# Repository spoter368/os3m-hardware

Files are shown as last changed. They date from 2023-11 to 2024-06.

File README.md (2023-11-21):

# os3m-hardware
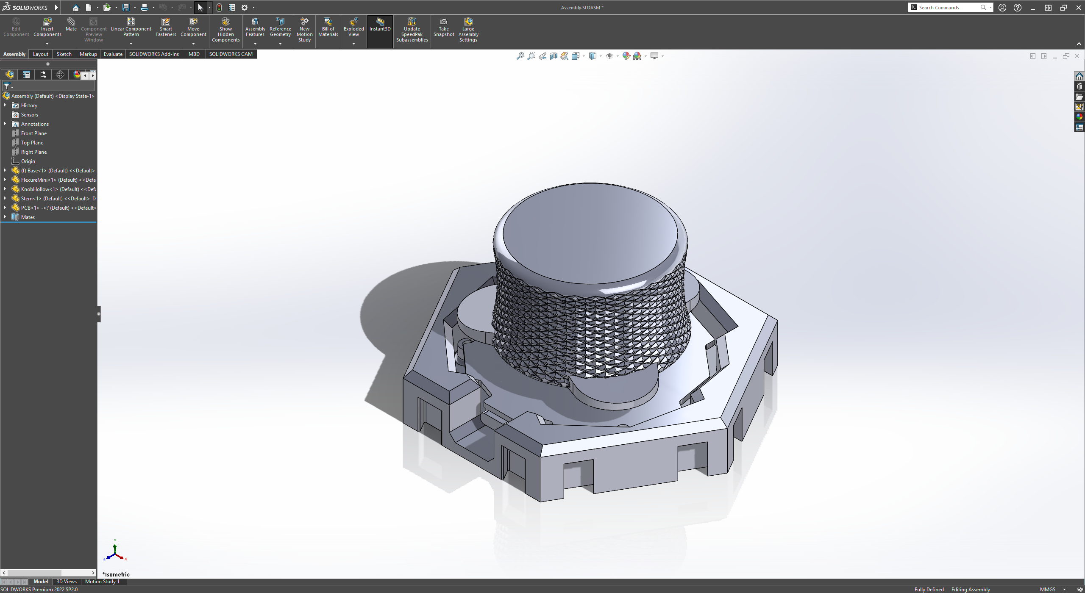
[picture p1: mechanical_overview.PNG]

Welcome to the mechanical repository of the OS3M mouse! Here you'll find all the pieces you need to make your own OS3M mouse, with the exception of 9 * M3x10 fasteners, the PCB and 3 dimes (USA 10 cent coin). I try to only commit and push when I have a fully compatible set of parts, so at any given time you should be able to clone this repo and build your own using its contents.

One of the beautiful things about this mouse is that if you don't like some aspect of it, you can just change it! Particularly when it comes to the flexure inside the mouse, if you want more or less stiffness, fork and edit away! Feel free to leave any issues in the issues tab as you find them.

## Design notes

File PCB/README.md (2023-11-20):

# OS3M Mouse PCB
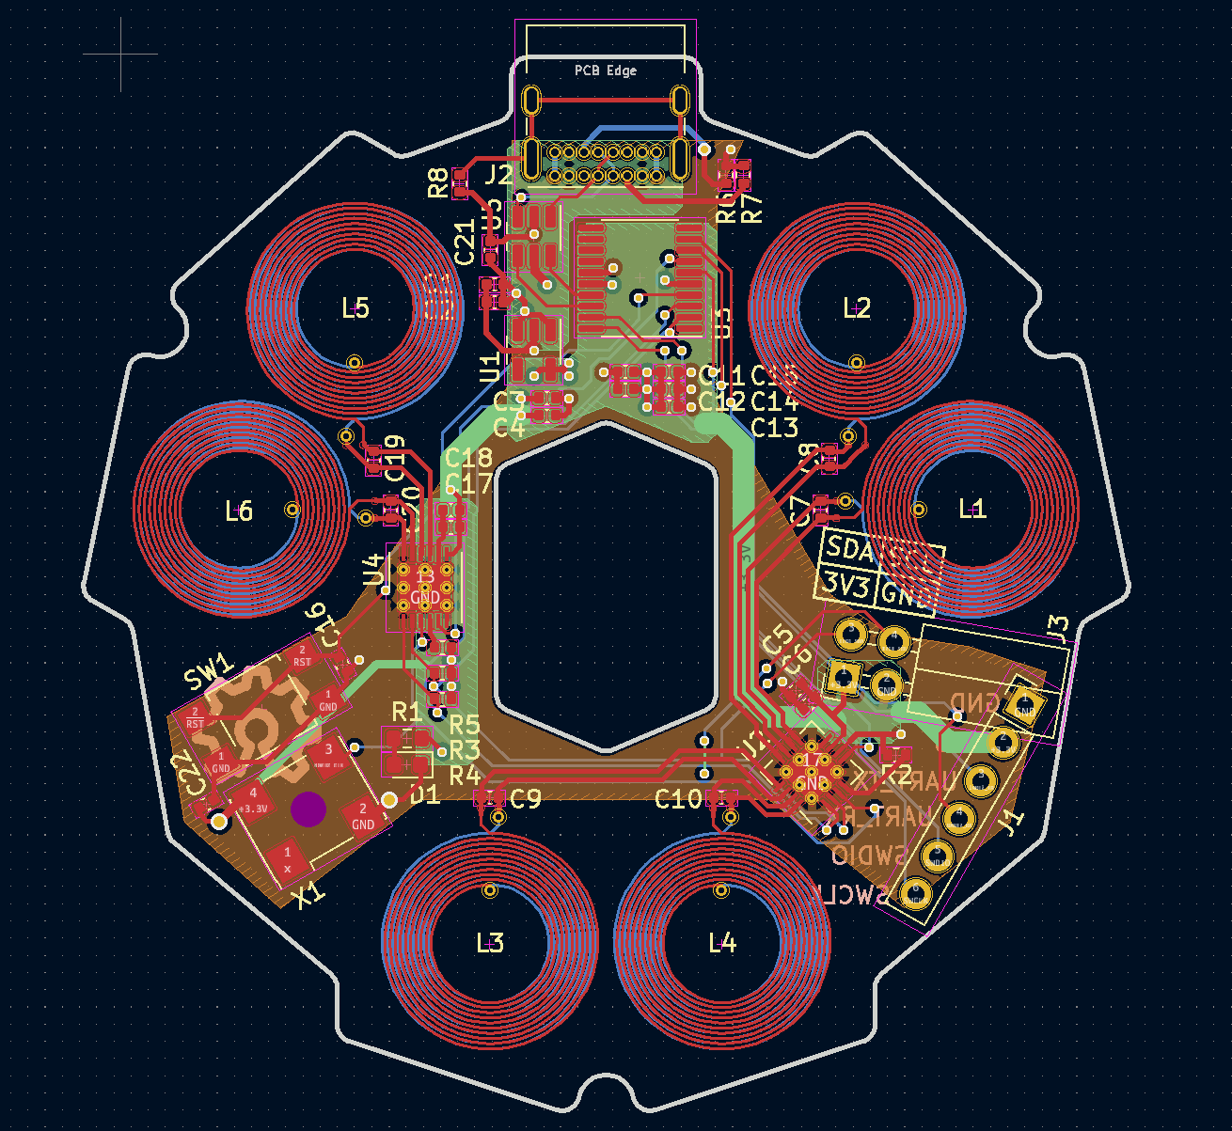
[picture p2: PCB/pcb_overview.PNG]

Here are all the files pertaining to the OS3M mouse's PCB. I only commit and push here when I have a full revision update to the PCB. So far there are only 2 revisions, 0 and 1, and you should only make the current one (1). Gerbers can be found in the os3m-gerbers folder, and can be sent to JLC for easy fab. I also plan on selling these on tindie at some point.

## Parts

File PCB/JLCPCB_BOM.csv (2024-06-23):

Comment | Designator | Footprint | JLCPCB Part# | Quantity
10u | C1, C4, C5, C17 | Capacitor_SMD:C_0402_1005Metric | C15525 | 4
1u | C2, C3, C6, C14, C16, C18 | Capacitor_SMD:C_0402_1005Metric | C52923 | 6
1n | C7, C8, C9, C10, C19, C20 | Capacitor_SMD:C_0402_1005Metric | C126493 | 6
10n | C11, C22 | Capacitor_SMD:C_0402_1005Metric | C15195 | 2
100n | C12, C13, C21 | Capacitor_SMD:C_0402_1005Metric | C1525 | 3
4.7u | C15 | Capacitor_SMD:C_0402_1005Metric | C23733 | 1
BLUE_LED | D1 | LED_SMD:LED_0603_1608Metric | C389520 | 1
200 | R1 | Resistor_SMD:R_0603_1608Metric | C22962 | 1
5.1k | R2, R3, R4, R5, R6, R7 | Resistor_SMD:R_0402_1005Metric | C25905 | 6
1M | R8 | Resistor_SMD:R_0402_1005Metric | C26083 | 1
SW_Push | SW1 | Button_Switch_SMD:SW_SPST_TL3305A | C92581 | 1
AP2112K-3.3 | U1 | Package_TO_SOT_SMD:SOT-23-5 | C51118 | 1
LDC1614 | U2 | Package_DFN_QFN:WQFN-16-1EP_4x4mm_P0.5mm_EP2.6x2.6mm_ThermalVias | C968448 | 1
STM32F042F6P6 | U3 | Package_SO:TSSOP-20_4.4x6.5mm_P0.65mm | C2969989 | 1
LDC1612 | U4 | Package_SON:WSON-12-1EP_4x4mm_P0.5mm_EP2.6x3mm_ThermalVias | C1847959 | 1
USBLC6-2SC6 | U5 | Package_TO_SOT_SMD:SOT-23-6 | C2687116 | 1
USB_C_Receptacle_USB2.0 | J2 | Connector_USB:USB_C_Receptacle_XKB_U262-16XN-4BVC11 | C319148 | 1
XTAL_40MHz | X1 | Oscillator:Oscillator_SMD_Abracon_ASV-4Pin_7.0x5.1mm | C558764 | 1

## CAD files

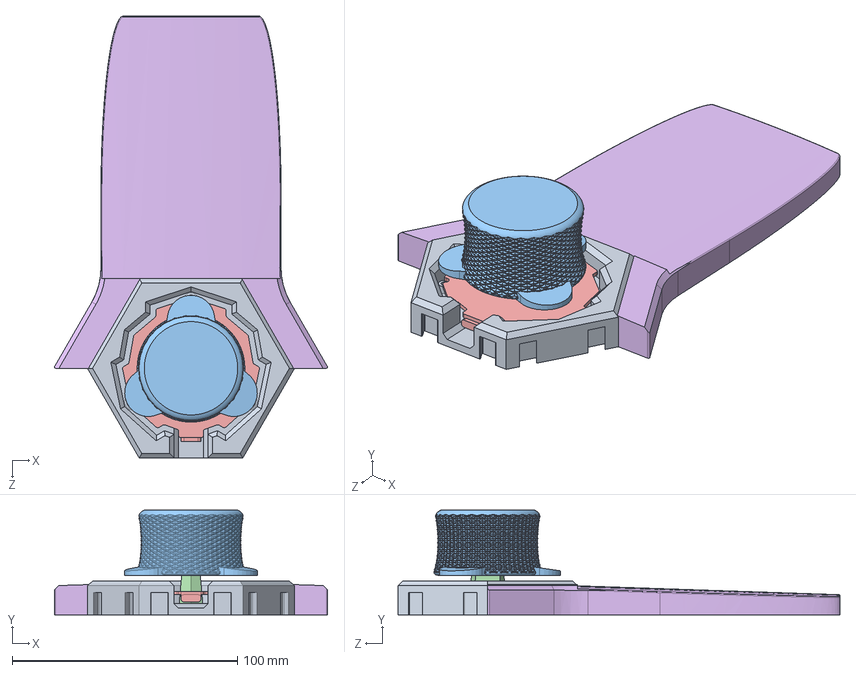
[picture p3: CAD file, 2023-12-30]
Assembly.SLDASM
121.3 x 46.6 x 196.2 mm
Base
FlexureMini
KnobHollow
Stem
PCB
HandRest

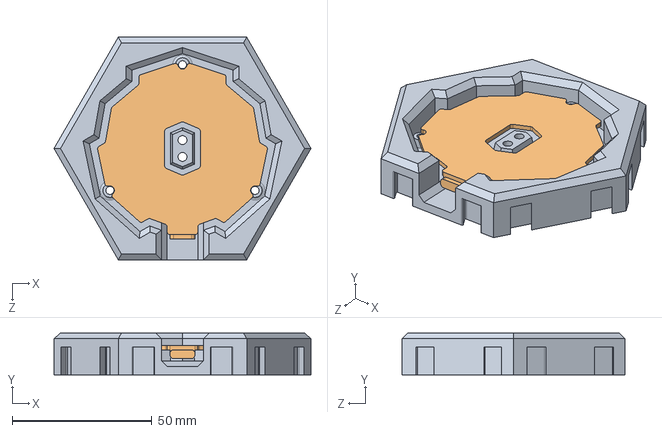
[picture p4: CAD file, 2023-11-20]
PCB_Assem.SLDASM
92.0 x 15.0 x 79.7 mm
Base
PCB

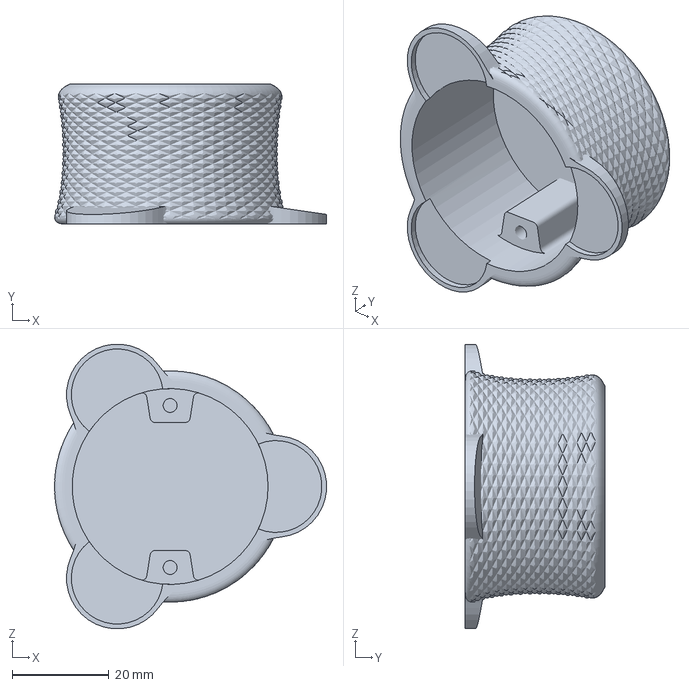
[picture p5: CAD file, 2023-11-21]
3MF Files/KnobHollow.3MF
56.2 x 29.0 x 58.8 mm

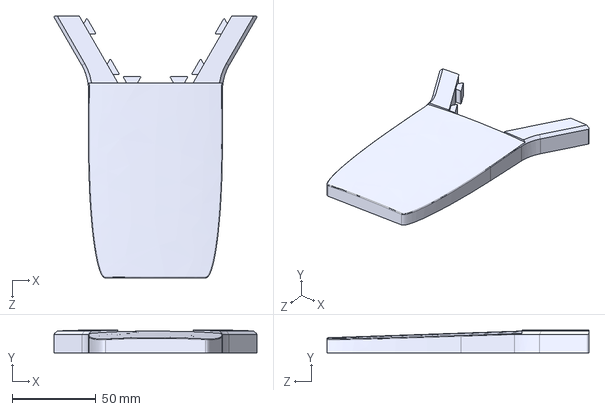
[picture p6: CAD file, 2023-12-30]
Step Files/HandRest.STEP
121.3 x 13.5 x 156.4 mm

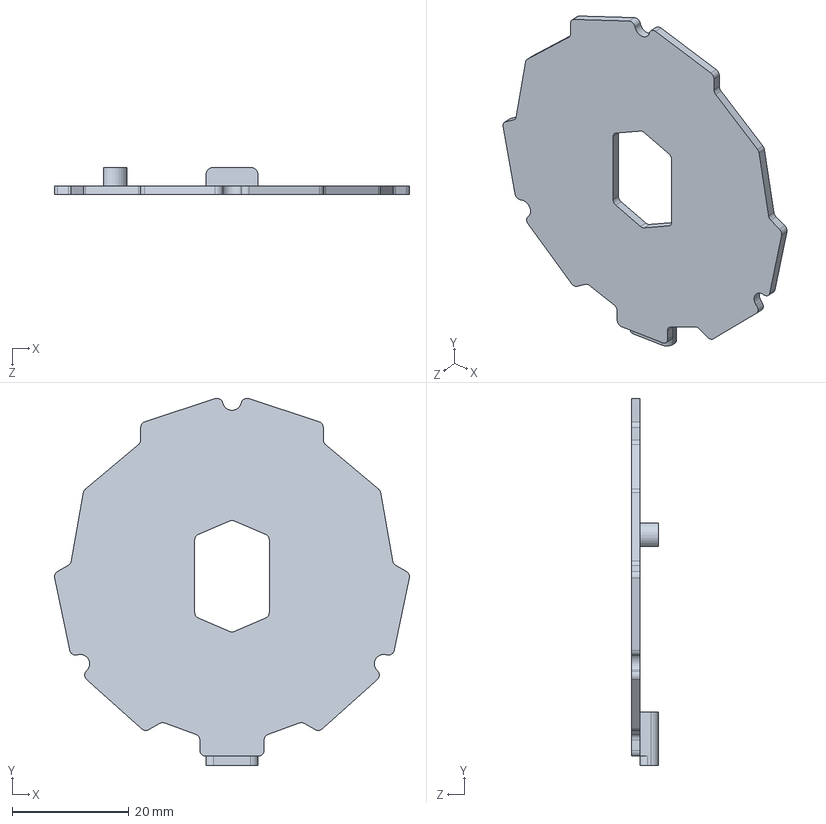
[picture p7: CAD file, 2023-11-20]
PCB.SLDPRT
60.8 x 62.9 x 4.67 mm

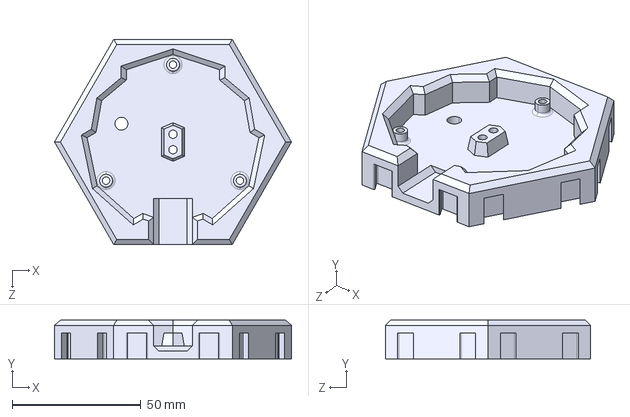
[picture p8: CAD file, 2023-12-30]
Step Files/Base.STEP
92.0 x 15.0 x 79.7 mm

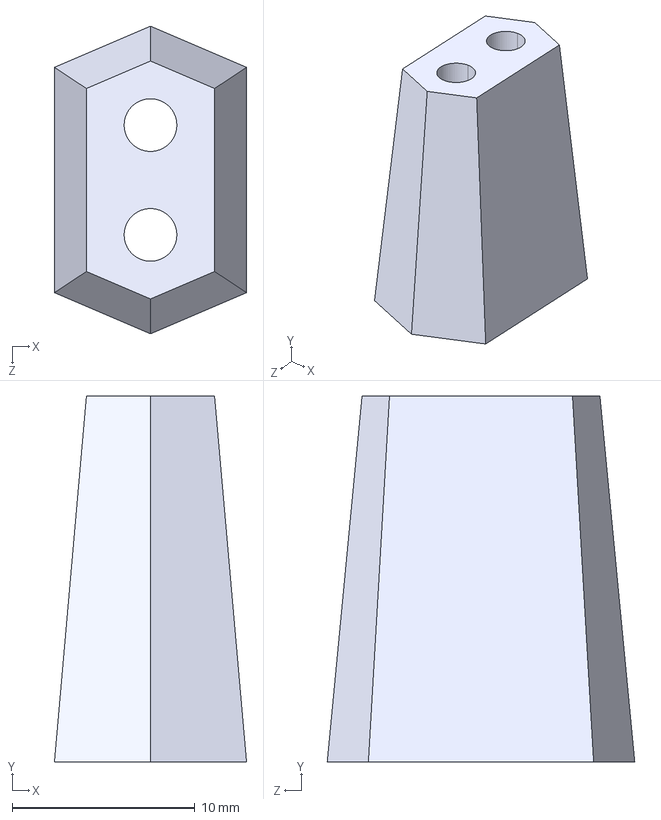
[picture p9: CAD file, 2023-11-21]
Step Files/Stem.STEP
10.5 x 20.0 x 16.8 mm

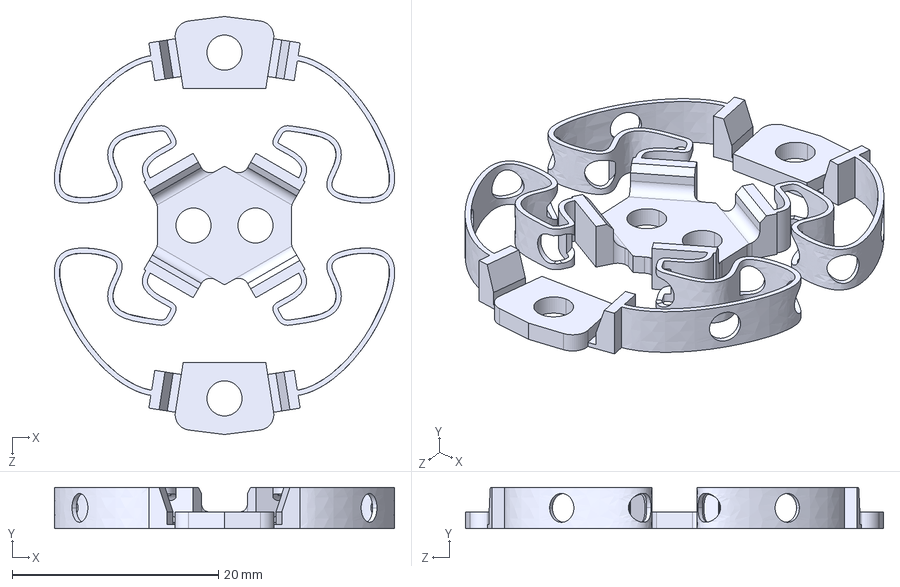
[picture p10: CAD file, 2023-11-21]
Step Files/FlexureMini.STEP
33.0 x 4.00 x 40.5 mm

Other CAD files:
3MF Files/Base.3MF
3MF Files/FlexureMini.3MF
3MF Files/HandRest.3MF
3MF Files/Stem.3MF
Base.SLDPRT
FlexureMini.SLDPRT
HandRest.SLDPRT
Stem.SLDPRT

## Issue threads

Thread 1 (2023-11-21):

Document software needed and BOM

MarcusWolschon, 2023-11-21:
Please document what software is needed to open the files.
My Alibre Design/3D Systems  Geomagic Design uses SLD_ASM and SLD_PRT too but refuses to open the files.

A Bill Of Meterials especially for the foreign coins needed would be useful too.

spoter368, 2023-11-21:
Just added STEP and 3MF files as well! SLDPRT and SLDASM files are for Solidworks, my CAD program of choice (though I know it's not the most open source friendly)

Kadah, 2023-12-11:
A BOM for the PCB components would be cool. I see #6 was just added submitted today, how convenient. :+1:

MarcusWolschon, 2023-12-13:
> Just added STEP and 3MF files as well! SLDPRT and SLDASM files are for Solidworks, my CAD program of choice (though I know it's not the most open source friendly)

Thanks.
However, I suggest to add that info to the .md instead. ;)

spoter368, 2023-12-27:
No, unfortunately the type-C connector I used has no equivalent on LCSC, so a redesign is needed for JLC to be able to build it. I plan on doing another hardware redesign as soon as this weekend to rectify that issue, though, so keep your eyes open for updates.

moth4017, 2023-12-27:
> No, unfortunately the type-C connector I used has no equivalent on LCSC, so a redesign is needed for JLC to be able to build it. I plan on doing another hardware redesign as soon as this weekend to rectify that issue, though, so keep your eyes open for updates.

thanks  for the update , there are a few of us who  have 3d printers  would like to build them , so  as soon as available from JLCPCB we are keen in ordering,  thanks for the reply .

moth4017, 2024-01-02:
do your updates get posted on your logs?

spoter368, 2024-01-02:
No, I just have been responding to issues here as needed. I updated the PCB this weekend so all parts can come from JLC only to find out LCSC is out of the LDC1612! I want to validate the PCB before I commit it here though so people don’t build defective systems. Will keep this ticket updated

JX5S, 2024-01-02:
LDC1612 is in stock, C202191, 289pcs. It's the LDC1614 that's a bit more problematic, only 67pcs

spoter368, 2024-01-03:
Ah, thank you! I promise they were out of stock this past weekend. I just placed my order for the updated board, and if it comes back and works, I will update the repo

spoter368, 2024-01-13:
@moth4017, I just published a release with the files needed to be assembled at JLCPCB

moth4017, 2024-01-15:
cheers Mark

Llybel, 2024-01-17:
> @moth4017, I just published a release with the files needed to be assembled at JLCPCB

Does this include the larger MCU your logs meantion needed? If not the stm32f103 is 64kb and is a preferred part for JLC which means it doesn't get the extended part fee added to PCB assembly costs.

spoter368, 2024-01-17:
Yes, this includes the larger MCU my logs mention. The STM32F103 is not an ideal choice for this project for a number of reasons, one being that it needs an external crystal to use the USB peripheral, rather than the STM32F042 I chose, which can use its internal clock for USB. Thanks for the suggestion though!

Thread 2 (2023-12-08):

Drivers?

krummrey, 2023-12-08:
I'd love to build one, but it seems that the driver side for OSX is missing, right?
Hopefully the project gains some momentum and some smart people come on board and complement the project to make it a usable solution.
Great start!

spoter368, 2023-12-10:
The driver is builtin to the firmware (available at https://github.com/spoter368/os3m-firmware). It is a USB HID device, which is supported by all modern OSs. The software script I wrote (here: https://github.com/spoter368/os3m-software) is currently Windows only, but all that does is convert the HID data (which any OS can receive) into solidworks API calls. It will become more advanced in the future though.

Closed 2023-12-10.

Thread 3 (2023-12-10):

Alternate inductor plane material - not US legal tender

SketchyFletchy, 2023-12-10:
Great concept! Small limitation for non-US citizens is that we don’t have convenient almost-flat discs of Nickel clad copper hanging around.

I’ll try a build just using some cutout thin copper sheet, which should do the job. I’ll give some thin iron strip a try too. Wouldn’t bother with aluminium though.

spoter368, 2023-12-10:
Thanks! I had no idea this project would be anywhere near as popular as it is, so hopefully you can forgive the use of "proprietary" materials ;)

Thin copper sheet should probably work, but will depend on the thickness. You'll need to make sure it's at least a few skin depths thick in order for the sensor to properly register its presence. My go-to resource for targets is TI app note SNOA957B, available here: https://www.ti.com/lit/an/snoa957b/snoa957b.pdf?ts=1702241246361

Section 4.2 actually mentions aluminum as an excellent target material, so I wouldn't rule that out. Best of luck on your build!

Kadah, 2023-12-11:
I wonder if a copper washer could work. An M8 one looks to be about 2mm smaller diameter and slightly thicker than a dime.

lpurdy01, 2024-01-02:
I wanted to do some research into what the best targets would be (even in the US I found it difficult to find dimes). So I built a rig to measure distance vs LDC response and then ran a bunch of targets through test sequences.

https://github.com/lpurdy01/os3m_target_testing

@spoter368 Based on the data I collected I made a hypothesis as to what I think the best target shape would be. The minimum order quantity from SendCutSend was 30. Email me at lpurdy01@<the google email service (gmail)>.com with an address if you want me to send you some.

During development I found non linearities that may make it very difficult to eliminate axis crosstalk in the steward platform solve. It may be a good idea to make a version with 4 sensor groups instead of 3. This would greatly simplify localization.

lpurdy01, 2024-01-29:
Some more progress on this issue!

I have made and tested a custom target. It is a great shape.
https://youtu.be/jGxCzWzAt6w
https://github.com/lpurdy01/os3m_target_testing

I am excited to try a knob with this target design.

Tropaion, 2024-02-25:
@spoter368 @lpurdy01 I was thinking of getting the knob slm printed in aluminium but then it occured to, the induction would probably not work anymore. What do you think? Would it be possible to get it to work?

lpurdy01, 2024-02-27:
I think it would work, but I think we have some refinement on the target distance before you would want to make something so expensive.

The aluminum would interfere a bit, mostly in rotation. As long as you made the bottom edge of the knob (facing the PCB) relatively thin ~1mm it shouldn't have enough surface area facing the coils to matter.

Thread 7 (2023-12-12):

Releases section and file order

Liam-Newell, 2023-12-12:
Hey I was just confused for a minute why the gerbers file wasn't in the sub folder mentioned in the readme then got more confused why the zip rev file wasn't a gerbers file. Took me a minute to understand where your PCB spec was.

Would recommend a small modification to where you're storing files and the file location in the READ.md **releases would make this easier** because you can just put all the required files in the file section of the readme.

spoter368, 2023-12-12:
I'm not sure what you mean... the readme says "Gerbers can be found in the os3m-gerbers folder" and if you go to "PCB/os3m-gerbers" that is where the gerbers are. I make no mention of zip files in the readme; they are only there so I can remember the state of the project when I released it (i.e. releases but before this project was uploaded to GitHub). Should there be another revision of the mouse, I'm open to using the releases feature of GitHub.

Closed 2023-12-12.

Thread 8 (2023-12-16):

Printing process documentation

Zufallsgenerat0r, 2023-12-16:
Could you provide some information on material's and settings used for printing?
Great project, thank you for the work.

Tropaion, 2024-03-02:
I also would like to know that. My spring is way to flexible, my knob is wobling even if not touched.

spoter368, 2024-03-02:
Used default 0.2mm layer, speed profile for the Prusa mini PLA. Turn off Arachne perimeter generation.

hotsgit, 2024-04-03:
This flexure modded by lpurdy01 is apparently easier to print: https://github.com/spoter368/os3m-hardware/pull/5

I used PLA+ (sometimes called PLA Pro or PLA Tough) with 0.4 or 0.6mm nozzle, 0.2mm layer. The higher print temperature than PLA mean it's less likely to creep/sag at room temperature. Creep _can_ happen to PLA under continuous force (but nobody has mentioned yet that it's an issue for this mouse).

I think PLA+ is less rigid than PLA but the flexure is plenty stiff for me, and I can't see the mouse wobble when I shake my table.

PETG is too flexible/inaccurate unless someone changes the model.

Tropaion, 2024-04-04:
I tried different materials and finally printed it with PLA-CF, got the overall best results with it.

hotsgit, 2024-04-08:
I know that's good for stiffness, but have you had any creep (sagging over time just from the weight of the knob) or cracking with PLA-CF? I'd kinda expect it. Now I've found even PLA+ creeps noticeable in the sensor readings for me when I leave the mouse sitting plugged in.
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

so I'll either design a flexure to be made out of PETG or go a different route and use nitrile O-rings. Currently testing whether O-rings creep under various stress levels.

hotsgit, 2024-04-14:
Update, nitrile O-rings won't work as precision springs. Even at just 132% stretch for 5 days I noticed permanent deformation where it wouldn't return to the original unstretched diameter (~3% increase).

Was curious whether time affected it, so I hooked an o-ring to a spring to test creep under nearly constant force:
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

Guess I should test PETG springs for that too.

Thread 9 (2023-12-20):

Floating BOOT0 Pin Causing Inconsistent Boot Entry Point

lpurdy01, 2023-12-20:
I was having problems the board inconsistently entering the bootloader or the flashed firmware.

The fix is to add a jumper that holds `PB8` (`BOOT0`) to GND. Optionally, on the next board revision a button and two resistors could be added to keep `PB8` low unless the button was pressed. This would allow the user to upload firmware to the `STM32 Bootloader` by holding the reset and `boot` buttons. It could be useful for the project to be able to distribute `.hex` files for users that don't have STLink devices to update their boards.

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

spoter368, 2023-12-20:
Ah, interesting. I ran into this bug too but it locked me in the bootloader only. Instead of modifying the hardware, I flashed the option bytes to ignore the BOOT0 pin value. If you're using STM32CubeProgrammer, simply change the BOOT_SEL option byte to be unchecked. No hardware mod necessary.

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

lpurdy01, 2023-12-20:
Cool fix. I will be applying that to my other board, so I don't have to mod it.

For me it was mostly only going into bootloader. I could only get it to boot normally when I fuzzed the power or held the pin low by measuring it with a multimeter. Thus the mod

spoter368, 2024-01-03:
As a note, the new revision of the PCB I just ordered (on 2024/1/2) has BOOT0 tied to GND. Once I validate this works, I'll close this issue

spoter368, 2024-01-13:
Fixed on the latest release and validated

Closed 2024-01-13.

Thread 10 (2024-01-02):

Overhauled boards

JX5S, 2024-01-02:
<p float="left">
  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
</p>

I've made several changes to the design, from what I remember:

- All components from LCSC (should be assembleable by JLC)
- Used components I prefer (button, USB-C)
- 0603 passives
- Reduced amount of component values
- Reduced amount of decoupling caps
- Changed debug header to only have power and SWD, same pinout as generic STM32 boards
- UART is on testpoints
- Set components that shouldn't be in CPL/BOM to not be there
- Changed routing
- Changed board thickness to 1.6mm and ensured there's 3D models for everything for CAD reasons
- Significantly reduced amount of DRC errors
- Added silkscreen around coils
- Added KiCad logo, changed OSHW logo

Impemented suggestions I've seen here:
- testpoints for some GPIOs
- fixed BOOT0

As a base I used master from from around 30.12.2023. Since the majority of changes are purely just my personal preference, the routing looks pretty bad, I haven't tested it and it might not be 100% compatible (it should be compatible, coils and board shape are identical, but programming header and USB-C etc aren't), should I do a pull request or just upload it to my account as an alternative board? I don't know when I'll get around to ordering it, it could be a matter of months

spoter368, 2024-01-03:
Wow! This is amazing! So glad to see others building on my work. If you validate this board, I'd be happy to call this V1.1 or something and approve a PR to make this the main board others work off of.

willie68, 2024-01-12:
That's nice.
As already entioned in #11., i have problems with my manufacturer with the original board. Is it possible that you can send/upload the kicad file to check with aisler? ([aisler.net](https://aisler.net)

JX5S, 2024-01-15:
Sorry, got busy with other stuff. I've uploaded the board files to my github if you want to check how I got rid of most of the warnings. This isn't an issue, I'll close it

Closed 2024-01-15.

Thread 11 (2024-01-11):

Aisler PCB manufacturer: shortend pads

willie68, 2024-01-11:
Hi,
i just wanted to order the pcb via aisler.com. (My favorite PCB manufacturer)
I uploaded the kicad PCB file and aisler checked it and found 6 shorted Pads.
Are these pads consciously connected? So is it save to order the board?
Here ist the original message:

```
We detected deviation(s) between the netlist and the processed layout of your pcb. At least one of the listed nets shares at least one pad, which is conductively connected the other net. Please check your layout before ordering. See also our [help article](https://community.aisler.net/t/smart-tests/52).
NET-(C8-PAD1), NET-(C8-PAD2)
NET-(C19-PAD1), NET-(C19-PAD2)
NET-(C20-PAD1), NET-(C20-PAD2)
NET-(C7-PAD1), NET-(C7-PAD2)
NET-(C9-PAD1), NET-(C9-PAD2)
NET-(C10-PAD1), NET-(C10-PAD2)
```

spoter368, 2024-01-12:
Hi Willie, I'd hold off on ordering the PCB just yet. I'm just finishing up debugging the latest version that can be fully assembled by JLCPCB and fixes some of the earlier problems with the board. Should be released tomorrow.

To answer your question though, yes, those pads are deliberately connected through the sensing coils on the PCB. I just am not experienced enough with KiCad to know how to tell it I did this on purpose :)

willie68, 2024-01-12:
Thanks for the reply.
I dont use Kicad, too. I've been using Target for what feels like forever.
But in target there is no Kicad importer, only one for eagle.
Do you plan to use github releases for the newest version?
(Which makes it much easier to get the right files)

spoter368, 2024-01-12:
I've never used them before, but I will do my best to use github releases going forward!

spoter368, 2024-01-13:
New PCB released via github releases workflow! Closing out this issue.

Closed 2024-01-13.

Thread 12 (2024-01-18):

Potential over-driving of the 40 MHz oscillator

dancollins, 2024-01-18:
This is an awesome design and, as part of the team in NZ keen on getting a few made at JLCPCB, I started reviewing the design. At this stage, just the layout and BOM. I noticed X1 is a 40 MHz oscillator being used to drive both the LDC1612 and LDC1614 devices and, for at least the JLCPCB BOM, is a YXC part: https://www.lcsc.com/product-detail/Oscillators_YXC-O705040MEDA4SC_C24796.html

Reading the datasheet, I note the oscillator output is rated to 15 pF - which isn't that much! Especially when driving the signal across the PCB as it is now.

Can I recommend updating the design? One option would be using a clock buffer to up the drive strength and adding series termination to cut down on reflections (40 MHz is pretty quick, and you're competing with just using the internal oscillators of the LDC161x parts). Another option could be using the microcontroller instead - the internal PLL could be tuned to (maybe not exactly) 40 MHz and used to drive the two inductive sensors. The upshot here is fewer clock sources (multiple oscillators can cause EMI problems, which you'd be really unlikely to see issues from on a small project), and you would also be free to use an STM32F103 part (just because they're really cheap and easy to get).

Keen to hear your thoughts around this, and whether you have tried probing the clock output with a scope? Note that scope probes are typically around 2 pF or so. If you're already right on the limit of that clock buffer then perhaps the scope would tip it over the edge.

spoter368, 2024-01-20:
Hi Dan!

Thanks for your in depth analysis of my design! Sounds like you've put more thought into it than I did, as I just used the first 40MHz oscillator with a decent PPM rating I could find on LCSC. I personally have not taken a scope reading of the CLK line, nor do I have the equipment necessary to perform such a measurement; however perhaps I could use a scope at work to do that on my own spare time. On the other hand though, I have already had the devices built with the oscillator I specified in the BOM and have confirmed they do work. I can't say for certain if I mass produced these that 100% of them would work, because as you said, they might be right on the edge of not working, but feel free to do any additional analysis you deem necessary and post the results here. I'd be happy to consider other options from LCSC.

As I mentioned in issue  #1 , I deliberately made the decision to use the STM32F042 over something cheaper and more available like the STM32F103 to simplify my design. Originally, I tried to get away with not using the 40MHz clock either, and just use the internal clock of the LDCs, but I found their noise level to be too high to have the mouse distinguish when a user is or is not using it (how it knows when to hone the axes to zero, see firmware for details). If people really believe the F103 is the way to go though, I might be open to redesigning it sometime in the future.

dancollins, 2024-01-21:
FWIW, this is a low-volume product and whether you use an F042 or F103 is neither here nor there. If it were me, I'd be on an nRF52840. I have much more experience on the ST parts (probably the last 15 years of my career is mostly ST), but the nRF part includes Bluetooth for a wireless option ;)

WRT the clocks - I figured there was a good reason you had an external clock. Did you consider crystals over an oscillator? No real reason there - and it's a little sad the LDC's don't have a clock-out option. I believe the F042 will have the same clocking options as the F103 (and every other ST-series part I've used!) so you could still explore that.

@Lybel is working on a fork with the F103, and doing the clock distribution I'd recommended. Basically just star-routing and series termination assuming about 50 ohms. We can adjust if needed, and I'll be collecting some scope traces as part of that. I reckon you're right that what you have will probably work totally fine - it's just the sort of comment I can't keep to myself when reviewing a design!

Really love your work, mate! You've inspired a group of us to do a fork - and I'll still be tempted to fork to the nRF52 ;)

dancollins, 2024-01-21:
I'll include our findings here. Naturally it wont include what you have now, but we'll be able to see how well our fork does (or doesn't!) work :)

lpurdy01, 2024-01-24:
I have one of the last revision with the old oscillator, and a 100Mhz oscope, so I wanted to provide some data to this conversation.
[At_LDC1612.csv](https://github.com/spoter368/os3m-hardware/files/14034860/At_LDC1612.csv)
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
[At_LDC1612_csv.txt](https://github.com/spoter368/os3m-hardware/files/14034861/At_LDC1612_csv.txt)
[At_LDC1612_png.txt](https://github.com/spoter368/os3m-hardware/files/14034864/At_LDC1612_png.txt)
[At_LDC1614.csv](https://github.com/spoter368/os3m-hardware/files/14034865/At_LDC1614.csv)
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
[At_LDC1614.txt](https://github.com/spoter368/os3m-hardware/files/14034866/At_LDC1614.txt)
[At_LDC1614_png.txt](https://github.com/spoter368/os3m-hardware/files/14034868/At_LDC1614_png.txt)
[At_OSC.csv](https://github.com/spoter368/os3m-hardware/files/14034870/At_OSC.csv)
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
[At_OSC_csv.txt](https://github.com/spoter368/os3m-hardware/files/14034872/At_OSC_csv.txt)
[At_OSC_png.txt](https://github.com/spoter368/os3m-hardware/files/14034873/At_OSC_png.txt)

These were captured with AC coupling 1.0 GS/s. (I don't have any of those nifty spring probes around to do a DC capture, and the ground lead would cause far too many problems.)

 From the OSC to the LDC1614 (across the board) it does look like the `[rise_time, fall_time]` increases from `[1.3ns,1.9ns]` to `[2.7ns,3.6ns]`. The datasheet for the ASV-40.000MHZ-EC-T says a typical Tr or Tf is 2.4ns to a max of 4.0ns.

 The ASV-40.000MHZ-EC-T has the same output load rating as the new O705040MEDA4SC. 15pF

 I would suspect it manages this only because it looks like @spoter368 put a lot of effort into minimizing the coverage of the ground planes, so there isn't much capacitance in the board.

 @dancollins, @Llybel, Could you take a look at these graphs and see if you can glean more out of them?

Tropaion, 2024-02-25:
> Really love your work, mate! You've inspired a group of us to do a fork - and I'll still be tempted to fork to the nRF52 ;)

I can't say much about the oscillation topic since I'm working more in the digital area, but an version with bluetooth, either nRF52 or preffered ESP32 would be really nice.

Duckle29, 2024-07-17:
Be aware that most scope probes have quite a bit of capacitance.
Usually around 18pF so would on their own load the circuit too much. Even our R&S 500MHz passive probes are 12pF.

For measuring crystals you really should have <2pF if not even lower and you don't really get that until you go to quite expensive ghz bandwidth probes

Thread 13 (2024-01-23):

Optimal thickness of PCB?

nullstalgia, 2024-01-23:
Howdy howdy.

I was thinking about picking up a copy of the latest revision alongside my latest JLCPCB order, but I'm unsure as to what thickness is best for this!

Because most USB-C ports I've run into don't fully fill a 1.6mm deep through hole, I usually choose a 1.0mm board when designing PCBs with USB-C. And when trying to figure out what to order here, I got stuck since I found no reference to PCB thickness other than a PR, and the Physical Stackup defined in KiCad results in a ~5mm thick PCB :P
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

So I'm assuming most people have ordered 1.6mm, but I wanted to be sure.

spoter368, 2024-01-23:
Hi! The JLC build works fine at 1.6mm, that’s the thickness I ordered mine at and it came back with no issues. Changing the thickness to anything else could result in some weirdness of the sensing coil parameters, so I’d be hesitant to do that.

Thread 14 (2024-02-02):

Missing Parts in BOM

Overlord6644, 2024-02-02:
The parts J1 and J3 are not listed in the BOM.
It's intended or an error ?
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

Closed 2024-02-04.

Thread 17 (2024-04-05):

Ferrite "Core" to Direct Magnetic Field

hotsgit, 2024-04-05:
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

100% of commercial inductive sensors have ferrite cores to strengthen and direct the oscillating magnetic field while reducing interference. Based on the diagrams below you can see how the geometry of the core directs the field.

There's generally 2 kinds, flush and non-flush, with the only difference being the coil/core design:

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
(Source: https://www.altechcorp.com/HTML/Sensors_Standard-A.html)

The OS3M PCB coils are thin and can't have a core in/around the coils, but it would still be an improvement to include a 12mm (1/2") wide ferrite disc below each of the coils to strengthen the field and reduce interference. Ferrite is the ideal material because it redirects fields while reducing losses in the oscillating magnetic fields (hysteresis).

In my country I could only find decent 12x3mm magnets on aliexpress (ferrite, non-flexible and non-neodym.). I'll first run them through a cheap demagnetizer (doubt that will be enough), otherwise will try to heat past 250°C (source: https://www.magnet-shop.com/lexikon/demagnetise-permanent-magnet). Will update on the results.

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

I'm already experiencing way less sensor noise by clamping a steel gear to the base of my OS3M mouse, but it's far from ideal.
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

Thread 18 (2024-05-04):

Jlcpcb order help

how-eee, 2024-05-04:
Could you please describe what options we need there.
And how to order assembled pcb.
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

kamilkara, 2024-06-18:
Great project! Thanks for sharing this with the community.

I also would like to know how to order assembled pcb. Do you also have a plan for updating soon regarding #19, please?

Thanks a lot.

spoter368, 2024-06-23:
Hi @kamilkara , you can simply use the default settings with the exception of making it a 4 layer board.

I will update and resolve #19 soon

Closed 2024-06-23.

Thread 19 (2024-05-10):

JLCPCB parts out of stock

Nanotech45, 2024-05-10:
Upon going to order the assembled PCB via JLCPCB, they notified me that two components are out of stock:

SW1 - SW_Push - Button Switch
X1 - XTAL_40MHz - 40 MHz Oscillator

The button switch looks like it will be easy to source an alternative. After attempting to pre-order the 40 MHz oscillator, they informed me that the manufacturer has discontinued that part number. It looks like a replacement part will need to be sourced.

@spoter368

spoter368, 2024-06-23:
I haven't vetted the components myself, but going off the datasheet, the parts I just pushed to the BOM should work

Closed 2024-06-23.

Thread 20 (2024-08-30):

Component placement errors (?)

keab, 2024-08-30:
Hi
I'm about to order assembled PCB:s from JLPCB and used the files from this repo without any modification.  However several components are on the "preview" turned 90 deg and the USB connector is sligthly displaced. Anyone else had this problem? Is the preview incorrect or am I the first one to order like this?

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

keab, 2024-09-17:
If it helps anyone, here is a modded position file which works with JLCPCB:
[OS3M_Mouse-top-pos_JLCPCB.csv](https://github.com/user-attachments/files/17024094/OS3M_Mouse-top-pos_JLCPCB.csv)

And a modded BOM using the "DNTT"-version of the 2-channel sensor (the other version was out of stock). It's a bit unclear what the difference really is, but according to Digikey the DNTT has a maximum sample rate of 1 kSps, which should not cause any problem.
[JLCPCB_BOM_DNTT.csv](https://github.com/user-attachments/files/17024131/JLCPCB_BOM_DNTT.csv)

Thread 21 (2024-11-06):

PCB proposals for next release

keab, 2024-11-06:
Some proposals based on my experiences with the PCB:

1.  Add a resistor (1k?) between STM32 pin 1 and GND. This would make it possible to connect the boot pin to 3.3V without de-soldering, if ever needed. I managed to erase the bootN setting by clicking the  "Read unprotect" checkbox in the STM tool, and had to lift pin 1 to get it into boot mode. Even better if a test pad could also be connected to pin 1.

2. Add a layout on the bottom side for an SPST switch between UART RX and TX, for easier reprogramming. (With a matching hole in the mechanics)

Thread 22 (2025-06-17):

Measuring spring extension using inductive sensing

fermino, 2025-06-17:
Lately I've been doing some reading around the project and found this article quite interesting, I want to do some experiments around it and thought I might share it here in case anyone else finds it useful :)

https://www.ti.com/lit/ta/ssztch7/ssztch7.pdf

Starting with a spring based stewart platform (without downplaying the current approach, which is quite impressive), all 6 springs lenghts could be measured in a more direct way, which should make signal post-processing a lot simpler, in theory.

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

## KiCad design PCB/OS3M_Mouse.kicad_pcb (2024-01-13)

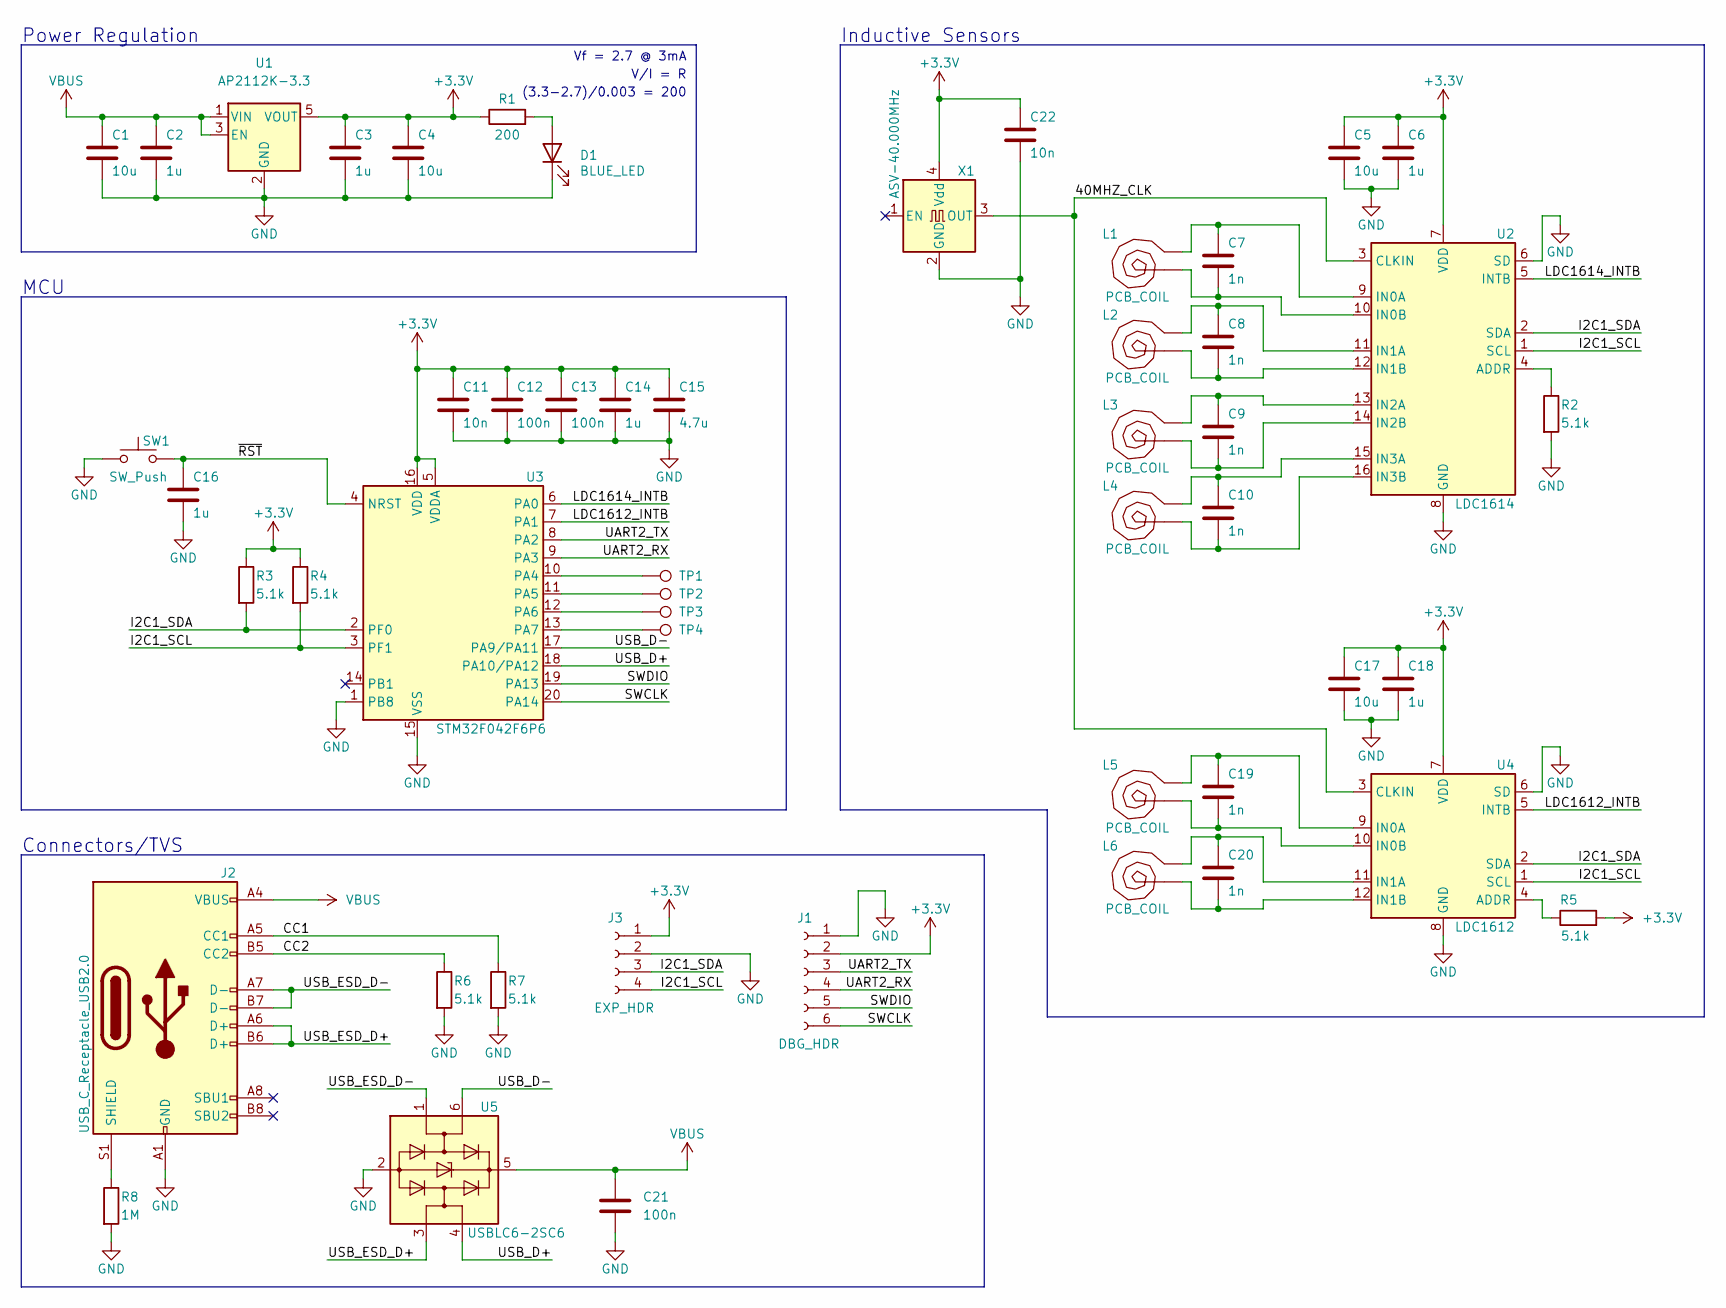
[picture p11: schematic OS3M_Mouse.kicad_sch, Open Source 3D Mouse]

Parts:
C1, C4, C5, C17: 10u; C_0402_1005Metric
C2, C3, C6, C14, C16, C18: 1u; C_0402_1005Metric
C7, C8, C9, C10, C19, C20: 1n; C_0402_1005Metric
C11, C22: 10n; C_0402_1005Metric
C12, C13, C21: 100n; C_0402_1005Metric
C15: 4.7u; C_0402_1005Metric
D1: BLUE_LED; LED_0603_1608Metric
J1: DBG_HDR; PinHeader_1x06_P2.54mm_Vertical
J2: USB_C_Receptacle_USB2.0; USB_C_Receptacle_XKB_U262-16XN-4BVC11
J3: EXP_HDR; PinSocket_2x02_P2.54mm_Horizontal
L1, L2, L3, L4, L5, L6: PCB_COIL; COIL_GENERATOR_0
R1: 200; R_0603_1608Metric
R2, R3, R4, R5, R6, R7: 5.1k; R_0402_1005Metric
R8: 1M; R_0402_1005Metric
SW1: SW_Push; SW_SPST_TL3305A
TP1, TP2, TP3, TP4: TestPoint; TestPoint_Pad_D2.0mm
U1: AP2112K-3.3; SOT-23-5
U2: LDC1614; WQFN-16-1EP_4x4mm_P0.5mm_EP2.6x2.6mm_ThermalVias
U3: STM32F042F6P6; TSSOP-20_4.4x6.5mm_P0.65mm
U4: LDC1612; WSON-12-1EP_4x4mm_P0.5mm_EP2.6x3mm_ThermalVias
U5: USBLC6-2SC6; SOT-23-6
X1: ASV-40.000MHz; Oscillator_SMD_Abracon_ASV-4Pin_7.0x5.1mm

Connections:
+3.3V: C3.1, C4.1, C5.1, C6.1, C11.1, C12.1, C13.1, C14.1, C15.1, C17.1, C18.1, C22.1, J1.2, J3.1, R1.1, R3.1, R4.1, R5.2, U1.5 (VOUT), U2.7 (VDD), U3.5 (VDDA), U3.16 (VDD), U4.7 (VDD), X1.4 (Vdd)
/40MHZ_CLK: U2.3 (CLKIN), U4.3 (CLKIN), X1.3 (OUT)
/CC1: J2.A5 (CC1), R7.1
/CC2: J2.B5 (CC2), R6.1
/I2C1_SCL: J3.4, R4.2, U2.1 (SCL), U3.3 (PF1), U4.1 (SCL)
/I2C1_SDA: J3.3, R3.2, U2.2 (SDA), U3.2 (PF0), U4.2 (SDA)
/LDC1612_INTB: U3.7 (PA1), U4.5 (INTB)
/LDC1614_INTB: U2.5 (INTB), U3.6 (PA0)
/SWCLK: J1.6, U3.20 (PA14)
/SWDIO: J1.5, U3.19 (PA13)
/UART2_RX: J1.4, U3.9 (PA3)
/UART2_TX: J1.3, U3.8 (PA2)
/USB_D+: U3.18 (PA10/PA12), U5.4 (I/O2)
/USB_D-: U3.17 (PA9/PA11), U5.6 (I/O1)
/USB_ESD_D+: J2.A6 (D+), J2.B6 (D+), U5.3 (I/O2)
/USB_ESD_D-: J2.A7 (D-), J2.B7 (D-), U5.1 (I/O1)
/~RST: C16.1, SW1.2, U3.4 (NRST)
GND: C1.2, C2.2, C3.2, C4.2, C5.2, C6.2, C11.2, C12.2, C13.2, C14.2, C15.2, C16.2, C17.2, C18.2, C21.2, C22.2, D1.1 (K), J1.1, J2.A1 (GND), J2.A12 (GND), J2.B1 (GND), J2.B12 (GND), J3.2, R2.2, R6.2, R7.2, R8.2, SW1.1, U1.2 (GND), U2.6 (SD), U2.8 (GND), U2.17 (GND), U3.1 (PB8), U3.15 (VSS), U4.6 (SD), U4.8 (GND), U4.13 (GND), U5.2 (GND), X1.2 (GND)
unnamed: C7.1, L1.1, U2.9 (IN0A)
unnamed: C7.2, L1.2, U2.10 (IN0B)
unnamed: C8.1, L2.1, U2.11 (IN1A)
unnamed: C8.2, L2.2, U2.12 (IN1B)
unnamed: C9.1, L3.1, U2.13 (IN2A)
unnamed: C9.2, L3.2, U2.14 (IN2B)
unnamed: C10.1, L4.1, U2.15 (IN3A)
unnamed: C10.2, L4.2, U2.16 (IN3B)
unnamed: C19.1, L5.1, U4.9 (IN0A)
unnamed: C19.2, L5.2, U4.10 (IN0B)
unnamed: C20.1, L6.1, U4.11 (IN1A)
unnamed: C20.2, L6.2, U4.12 (IN1B)
unnamed: D1.2 (A), R1.2
unnamed: J2.S1 (SHIELD), R8.1
unnamed: R2.1, U2.4 (ADDR)
unnamed: R5.1, U4.4 (ADDR)
unnamed: TP1.1, U3.10 (PA4)
unnamed: TP2.1, U3.11 (PA5)
unnamed: TP3.1, U3.12 (PA6)
unnamed: TP4.1, U3.13 (PA7)
VBUS: C1.1, C2.1, C21.1, J2.A4 (VBUS), J2.A9 (VBUS), J2.B4 (VBUS), J2.B9 (VBUS), U1.1 (VIN), U1.3 (EN), U5.5 (VBUS)

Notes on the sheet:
Inductive Sensors
MCU
Power Regulation
(3.3-2.7)/0.003 = 200
V/I = R
Connectors/TVS
Vf = 2.7 @ 3mA

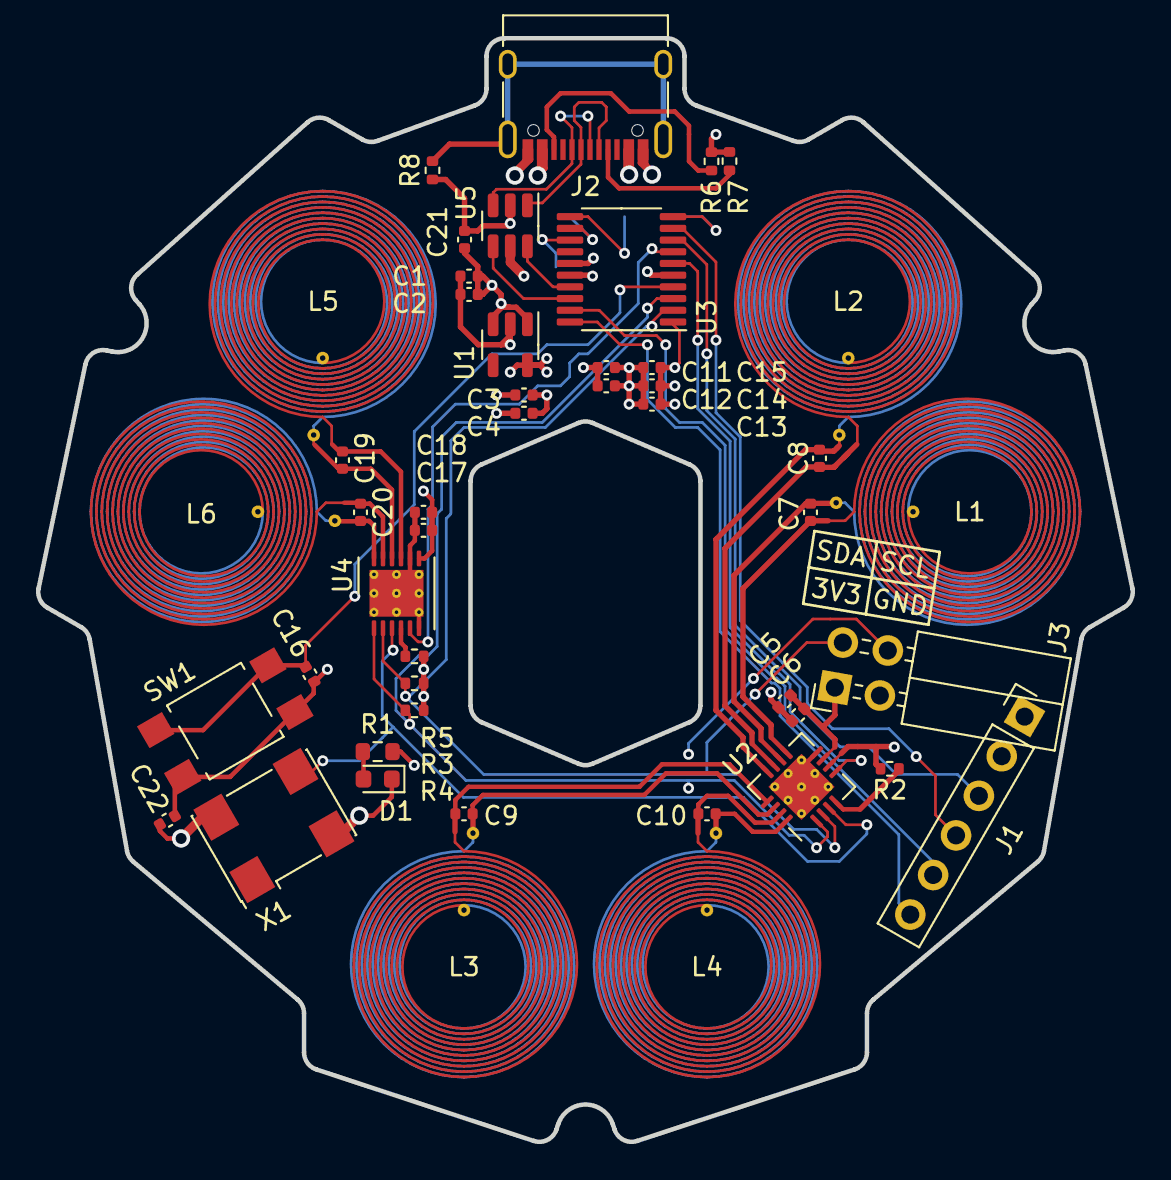
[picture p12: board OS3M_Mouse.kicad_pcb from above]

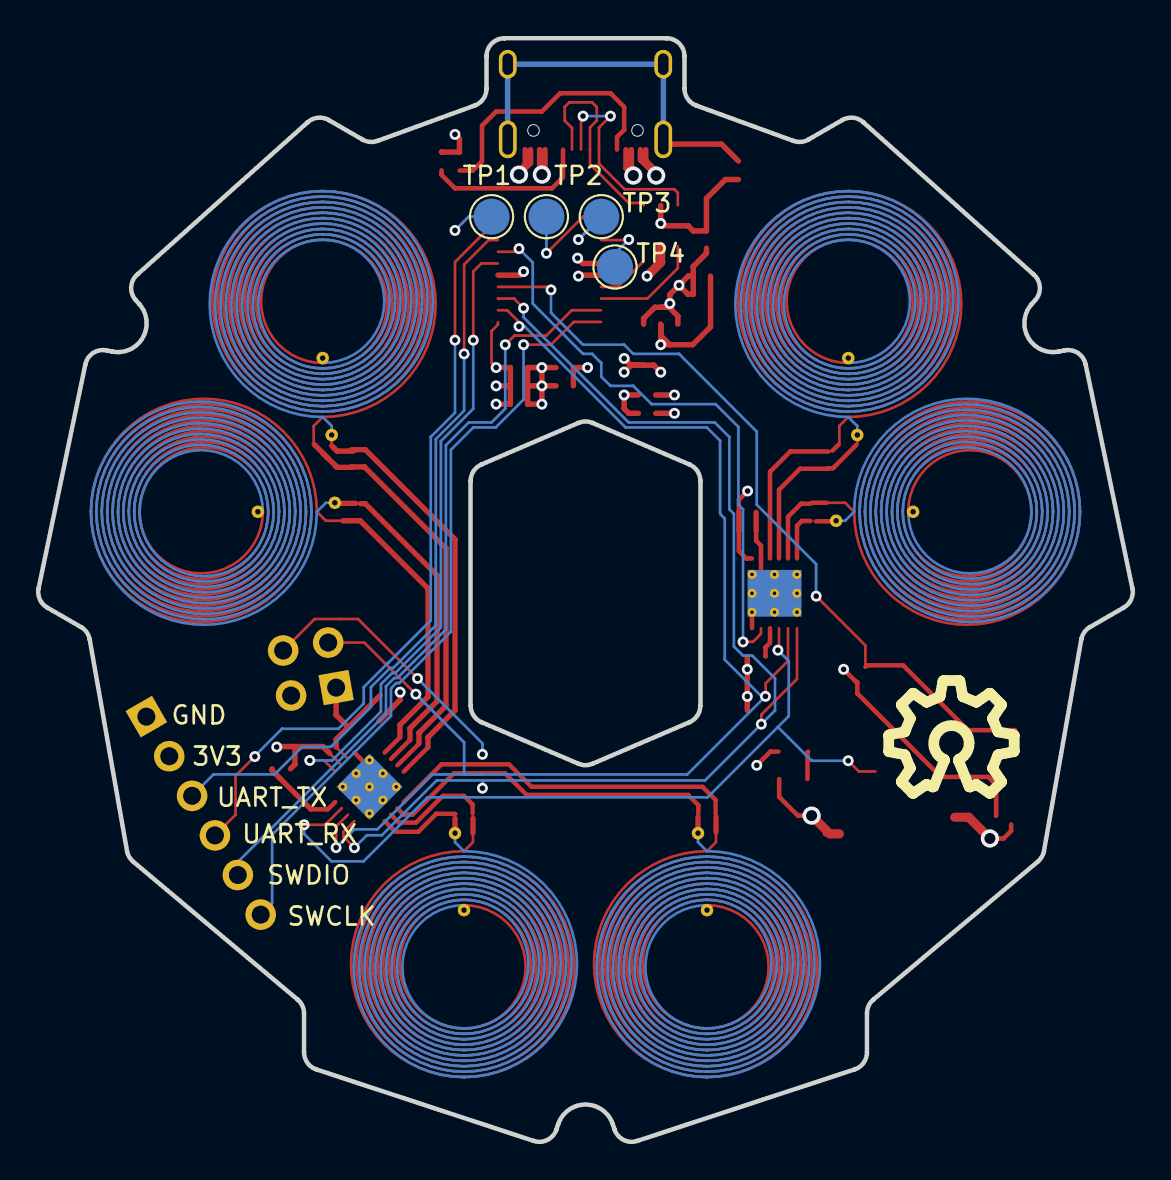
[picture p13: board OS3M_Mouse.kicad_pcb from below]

Board: 4 copper layers, 60.8 x 61.3 mm, 51 parts (4 on the bottom side), 39 nets.

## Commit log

2023-11-21 add step and 3mf files
    [Base.3MF, Base.STEP, FlexureMini.3MF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]
2023-12-11 Added BOM Files
    [DIGIKEY_BOM.csv, JLCPCB_BOM.csv]
2023-12-20 Fix shorted UART
    [OS3M_Mouse-B_Cu.gbl, OS3M_Mouse-B_Mask.gbs, OS3M_Mouse-B_Paste.gbp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]
2023-12-30 preliminary pass at wrist rest, fix base mounting points
    [Assembly.SLDASM, Base.3MF, Base.SLDPRT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]
2024-01-13 Update to Rev2, JLC manufacturable
    [JLCPCB_BOM.csv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]
2024-06-23 Replace switch and oscillator for #19
    [JLCPCB_BOM.csv]
